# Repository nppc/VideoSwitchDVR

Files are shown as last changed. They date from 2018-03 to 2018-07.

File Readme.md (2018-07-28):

# Control Board for Eachine Pro DVR (to install to EV100 Goggles)

Eachine Pro DVR using separate pins for input and output video signal. This makes it difficult to connect to EV100, where only one pin used for video in and out.

This board helps to automate the switching of video signal in DVR for playback or recording according to EV100 mode.

Also this board delays a startup of DVR for preventing cropping of PAL recording.

There is two additional pads (K1, K3), that can be used for controlling 2 buttons of DVR.

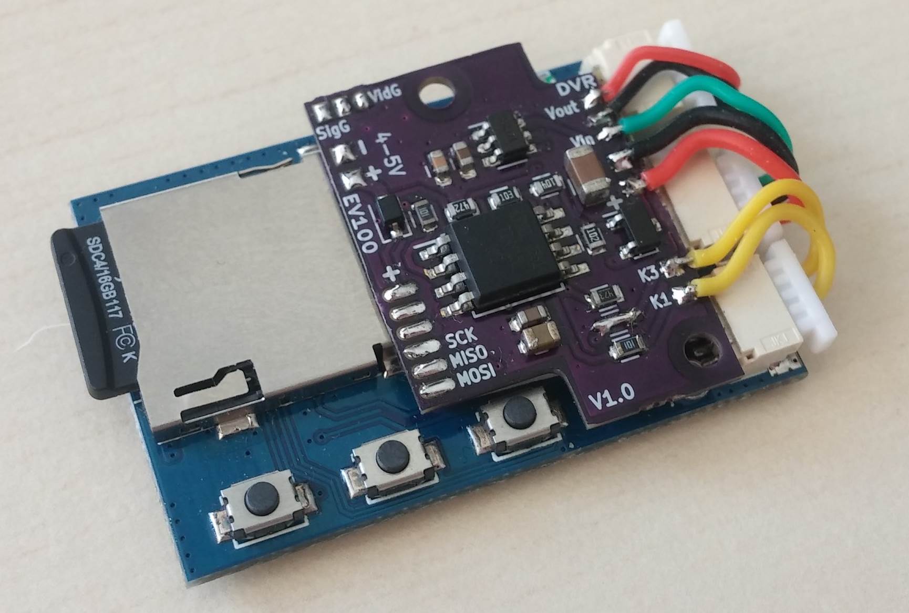
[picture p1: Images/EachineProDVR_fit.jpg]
DVR and PCB


## Current functionality
- When Goggles are powered, power to the DVR is delayed, preventing cropping of recorded video (known as PAL cropping issue).
- If Goggles is in normal mode (signal is coming from VRX), then DVR is receiving the VRX signal.
- If Goggles in AV mode (signal coming from AVin), then DVR starts to send own video to the Goggles.
- Stop recording when Goggles are powered OFF (need to add supercapacitor).
- DVR buttons control: (start recording on power on, switch recording/playback mode automatically).

## Current version of the board
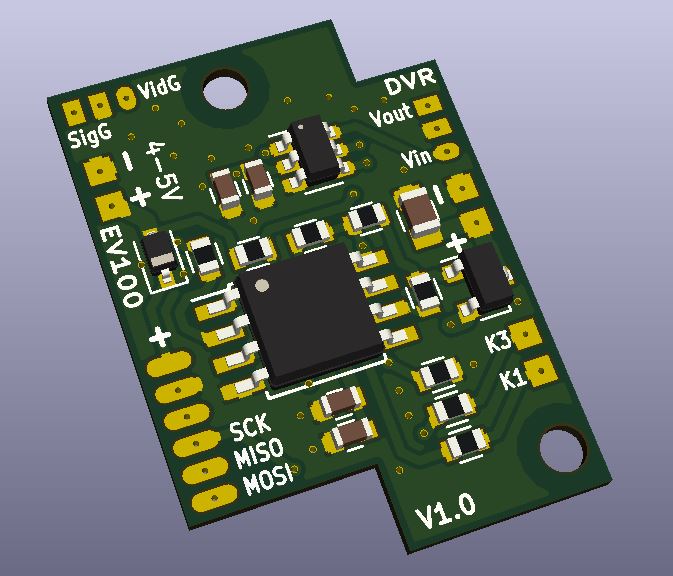
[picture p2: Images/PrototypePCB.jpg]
Current PCB


## Installed in the Goggles
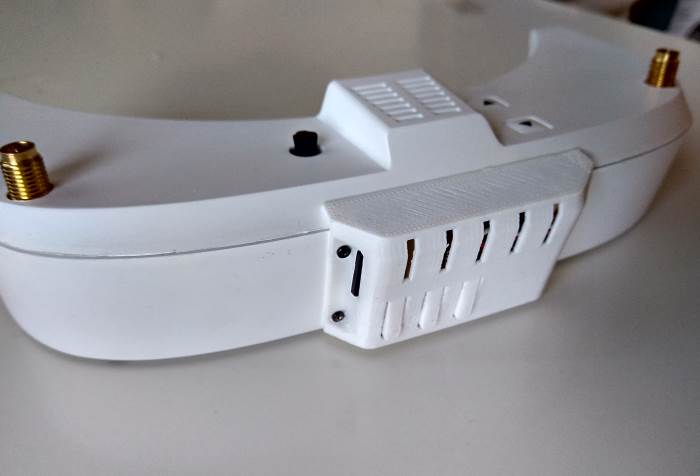
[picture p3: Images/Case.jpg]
printed box


## Power
I'm not sure how powerful is Goggle's DC/DC. So, it is safer to power DVR with additional DC/DC directly from Goggles battery.

Currently I'm using DIY 1A DC/DC with 5.2v output. It's switching frequency is 1.6Mhz, and has no noise in recorded video.
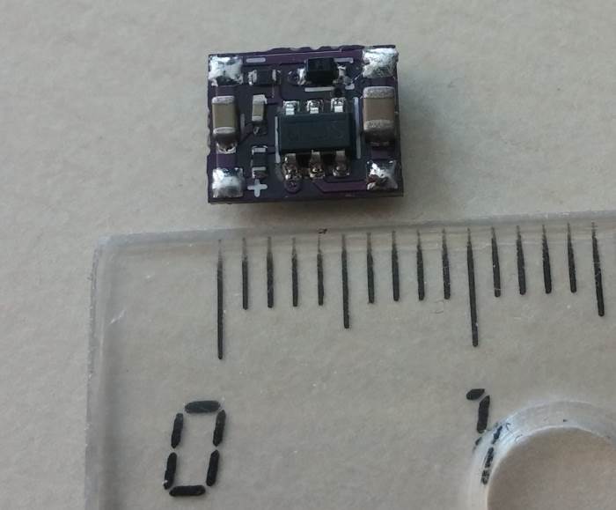
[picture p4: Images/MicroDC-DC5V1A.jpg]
Micro DC/DC 1A 5V


## Connection to the Goggles.
TODO.

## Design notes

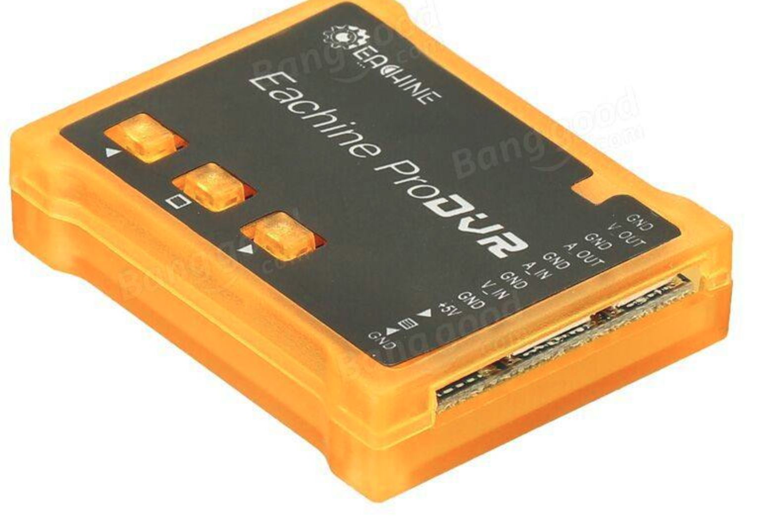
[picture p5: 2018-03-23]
Images/EachineProDVR_OriginalCase.jpg

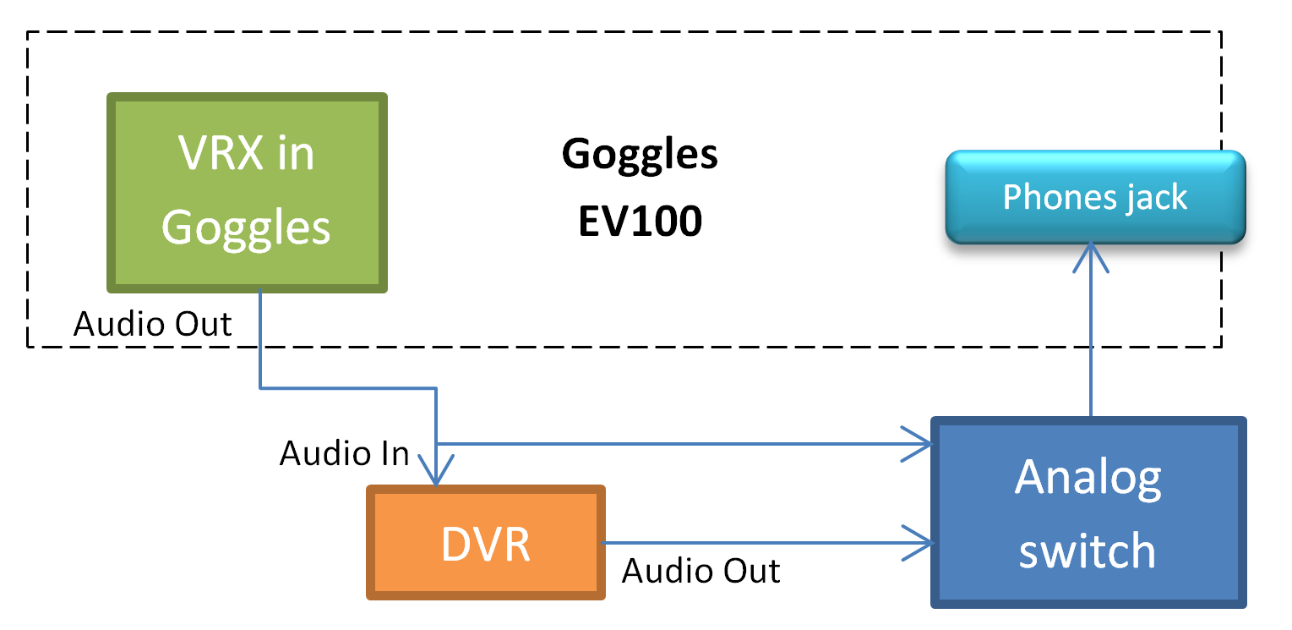
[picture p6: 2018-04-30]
Images/AudioIdea.png

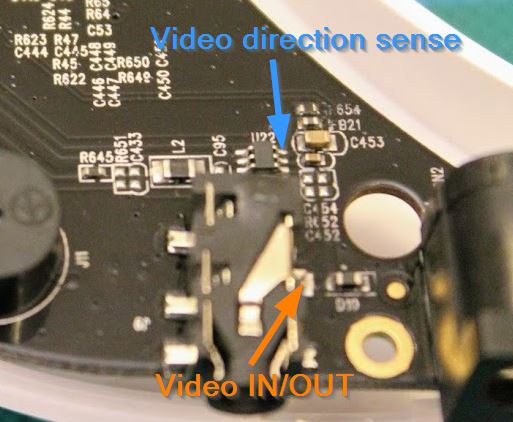
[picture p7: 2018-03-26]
Images/Goggles_connection.jpg

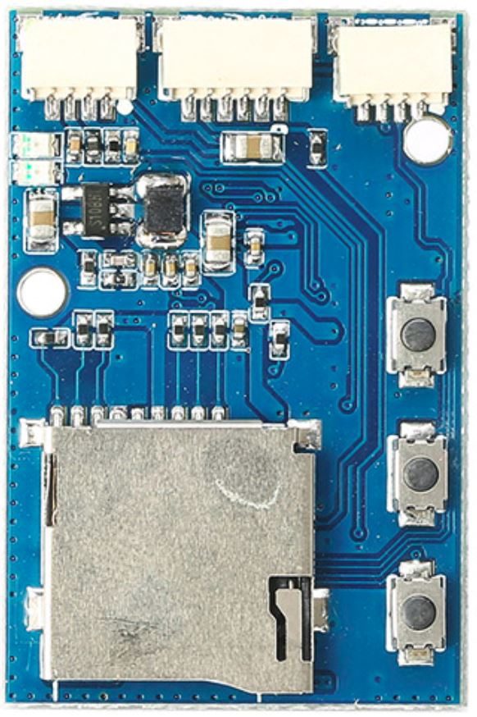
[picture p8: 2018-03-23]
Images/EachineProDVR_PCB.jpg

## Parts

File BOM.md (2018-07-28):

## Bill of Materials

Ref | Value | size/footprint
-------- | ---------------- | ----------
U1 | ATTINY25, ATTINY45 or ATTINY85 | SOIC8
U2 | MAX4624 | SOT-23-6
R2 | 100K | 0603
R4 | 100 | 0603
R6 | 1K | 0603
R7 | 4.7K | 0603
R8 | 47K | 0603
C1 | 10uf | 0603
C2, C3 | 100n | 0603
C4 | 10n | 0603
C5 | 22uf | 0805
D1 | B5819WS (or any with 1A If) | SOD-323
Q1 | AO3415 | SOT-23

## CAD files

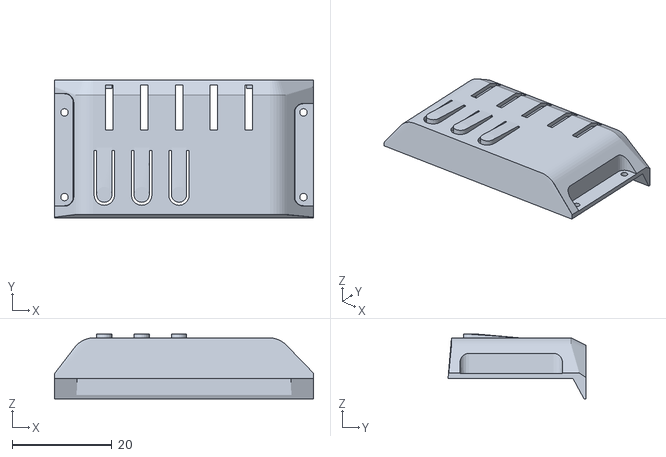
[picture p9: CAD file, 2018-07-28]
SCAD/Case2.stl
52.0 x 27.7 x 12.9

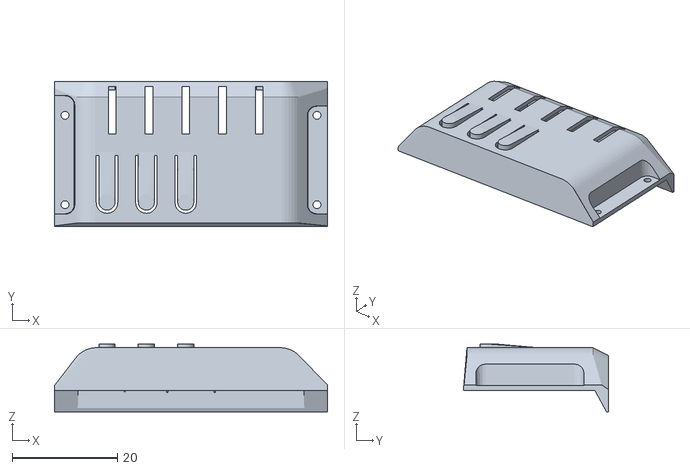
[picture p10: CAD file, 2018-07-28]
SCAD/Case.stl
52.0 x 27.7 x 12.9

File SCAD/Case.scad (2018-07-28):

$fn=20;
//electronics();
//translate([0,0,-25.5])rotate([-11.31,0,0])goggles();
fullcase();

module goggles(){
  color("white")translate([-50,-19,0])hull(){
    cube([100,0.1,20]);
    translate([0,25,5])cube([100,0.1,20]);
    translate([0,30,-1])cube([100,0.1,20]);
  }
}

module fullcase(){
  difference(){
  translate([0,0,1])difference(){
    union(){
      difference(){
        case(0);
        translate([0,0,-0.1])case(0.8); // make a bit thicker top wall
      }
      intersection(){
        case(0);
        union(){
          hull(){
            translate([26,12,0])cylinder(d=5,h=14,center=true);
            translate([26,-14,0])cylinder(d=5,h=14,center=true);
          }
          hull(){
            translate([-22,12,0])cylinder(d=5,h=14,center=true);
            translate([-22,-14,0])cylinder(d=5,h=14,center=true);
          }
        }
      }
      support();
    }
    // mounting holes
    hull(){
      translate([26,7,-2.2])cylinder(d1=3.5,d2=4,h=10);
      translate([26,-10,-2.2])cylinder(d1=3.5,d2=4,h=10);
      translate([30,7,-2.2])cylinder(d1=3.5,d2=4,h=10);
      translate([30,-10,-2.2])cylinder(d1=3.5,d2=4,h=10);
    }
      translate([26,7,0])cylinder(d=1.5,h=10,center=true);
      translate([26,-10,0])cylinder(d=1.5,h=10,center=true);
    hull(){
      translate([-22,9,-2.2])cylinder(d1=3.5,d2=4,h=10);
      translate([-22,-10,-2.2])cylinder(d1=3.5,d2=4,h=10);
      translate([-25,9,-2.2])cylinder(d1=3.5,d2=4,h=10);
      translate([-25,-10,-2.2])cylinder(d1=3.5,d2=4,h=10);
    }
      translate([-22,7,0])cylinder(d=1.5,h=10,center=true);
      translate([-22,-10,0])cylinder(d=1.5,h=10,center=true);

    // sdcard slot
    translate([-20,4.5,0.8])cube([10,12,2.2],center=true);
    
    //translate([0,0,-8.5])cube([100,100,10],center=true);
    //translate([-5,-20,-10])cube([100,100,20]);
  }
    //electronics();
    translate([-38/2+4/2+3,-25/2+4/2+0.9,0]){
      hull(){
        cylinder(d=4.1,h=10); //button
        translate([-4.1/2,5,0])cube([4.1,4,10]);
      }
      translate([7.5,0,0])hull(){
        cylinder(d=4.1,h=10); //button
        translate([-4.1/2,5,0])cube([4.1,4,10]);
      }
      translate([7.5*2,0,0])hull(){
        cylinder(d=4.1,h=10); //button
        translate([-4.1/2,5,0])cube([4.1,4,10]);
      }
    }
    translate([0,0,-25.5])rotate([-11.31,0,0])goggles();
    
    //***** ventilation
    for (i = [0 : 7 : 30] ){
      translate([i-13,8,5])cube([1.5,9,2], center=true);
    }
    /*
    // screw holes
    translate([38/2-7,-25/2+2,0])cylinder(d=1.5,h=5,$fn=20);
    translate([38/2-15.5,25/2-2,0])cylinder(d=1.5,h=5,$fn=20);
    */
    translate([-(20/2+24),0,0])cube([20,100,50],center=true);
    translate([(20/2+28),0,0])cube([20,100,50],center=true);
  }
  // PCB tabs
  //down
  translate([16,12.3,1.2+0.3])cube([3,1,2],center=true);
  translate([-14,12.3,1.2+0.3])cube([3,1,2],center=true);
  translate([19.7+0.5,12.3,-0.6])cube([2,1,2],center=true);
  //side
  hull(){
    translate([-19.1,-9,1.2+0.3])cube([1,3,2],center=true);
    translate([-19.6,-8,1.2+0.3])cube([0.1,3,2],center=true);
  }
  //***** buttons
  translate([-38/2+4/2+3,-25/2+4/2+1,5]){
    button();
    translate([7.5,0,0])button();
    translate([7.5*2,0,0])button();
  }
}


module support(){
  translate([2,-13.2,-2.5])cube([50,0.7,2],center=true);
  
  translate([2,-13.04,-0.1])cube([9,0.8,10],center=true);
  hull(){
  translate([2+9/2,-13.04,-0.1])cube([0.3,0.8,7.8],center=true);
  translate([2+9/2,13,-1+1])cube([0.3,0.8,7],center=true);
  }
  hull(){
  translate([2-9/2,-13.04,-0.1])cube([0.3,0.8,7.8],center=true);
  translate([2-9/2,13,-1+1])cube([0.3,0.8,7],center=true);
  }
  
  translate([-6.6,-12.6,2])cube([8,1.5,4.9],center=true);
  hull(){
  translate([-6.6-3.85,-13.04,1.8])cube([0.3,0.8,4.1],center=true);
  translate([-6.6-4,13,0])cube([0.3,0.8,7],center=true);
  }
}


module button(){
  hull(){
    cylinder(d=3.1,h=1.7); //button
    translate([-3.1/2,5.5,0])cube([3.1,4,1]);
  }
  translate([0,-0.2,-2.7])cylinder(d=2.6,h=2.7);
  
  hull(){
  translate([0,0,-2.7])cylinder(d=2.5,h=2.7);
  translate([0,4,0])cylinder(d=2,h=0.1);
  }
}

module case(wall){
  hull(){
    rotate([90,0,0]){
      translate([-16,0,3/2])cylinder(d=10-wall*2, h=27-3-wall*2,center=true,$fn=50);
      translate([19,0,3/2])cylinder(d=10-wall*2, h=27-3-wall*2,center=true,$fn=50);
      
      translate([-16,0,-(27-3-wall)/2])cylinder(d2=10-wall*2,d1=7-wall, h=3-wall,center=true,$fn=50);
      translate([19,0,-(27-3-wall)/2])cylinder(d2=10-wall*2,d1=7-wall, h=3-wall,center=true,$fn=50);
    }
    translate([2.5,-0.5,-7])cube([60-wall*2,28-wall*2,0.5],center=true);
  }
}

module electronics(){
  difference(){
    union(){
      DVRpcb();
      translate([13.5,-1,0])MYpcb();
    }
    translate([38/2-7,-25/2+2,0])cylinder(d=2,h=10,$fn=20,center=true);
    translate([38/2-7,-25/2+2,-3-0.5])cylinder(d=4,h=3,$fn=20);
    translate([38/2-15.5,25/2-2,0])cylinder(d=2,h=10,$fn=20,center=true);
    translate([38/2-15.5,25/2-2,-3-0.5])cylinder(d=4,h=3,$fn=20);
  }
}

module DVRpcb(){
  color("blue")cube([38,25,1], center=true); // pcb
  color("black")translate([0,0,-(0.5+1.5/2)])cube([36,23,1.5], center=true); // components
  color("lightgray")translate([38/2-1.5,0,(0.5+3/2)])cube([7,24,3], center=true); // connectors
  color("gray")translate([-38/2+15/2+1,25/2-15/2-2,(0.5+2/2)])cube([15,15,2], center=true); // cardreader
  color("black")translate([-38/2+10/2-2,25/2-10/2-3,(0.5+2/2)+0.4])cube([10,10,1], center=true); // sdcard
  
  translate([-38/2+4/2+3,-25/2+2.5/2+1,(0.5+1.5/2)]){
    color("gray")cube([4,2.5,1.5],center=true); //button
    color("black")cylinder(d=1.5,h=1,$fn=10);
  }
  translate([-38/2+4/2+3+7.5,-25/2+2.5/2+1,(0.5+1.5/2)]){
    color("gray")cube([4,2.5,1.5],center=true); //button
    color("black")cylinder(d=1.5,h=1,$fn=10);
  }
  translate([-38/2+4/2+3+7.5+7.5,-25/2+2.5/2+1,(0.5+1.5/2)]){
    color("gray")cube([4,2.5,1.5],center=true); //button
    color("black")cylinder(d=1.5,h=1,$fn=10);
  }
}

module MYpcb(){
  color("purple")translate([-38/2+15/2+1,25/2-15/2-2,(0.5+0.8/2)+2])cube([14,21,0.8], center=true); // cardreader
  color("purple")translate([-38/2+15/2+3.25+4,25/2-15/2-2.25-3.5,(0.5+0.8/2)+2])cube([9.5,21.5,0.8], center=true); // cardreader
  color("black")translate([-10,0,(0.5+1.8/2)+2.8])cube([6,6,1.8], center=true); // cardreader
  
}

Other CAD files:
SCAD/Case2.scad

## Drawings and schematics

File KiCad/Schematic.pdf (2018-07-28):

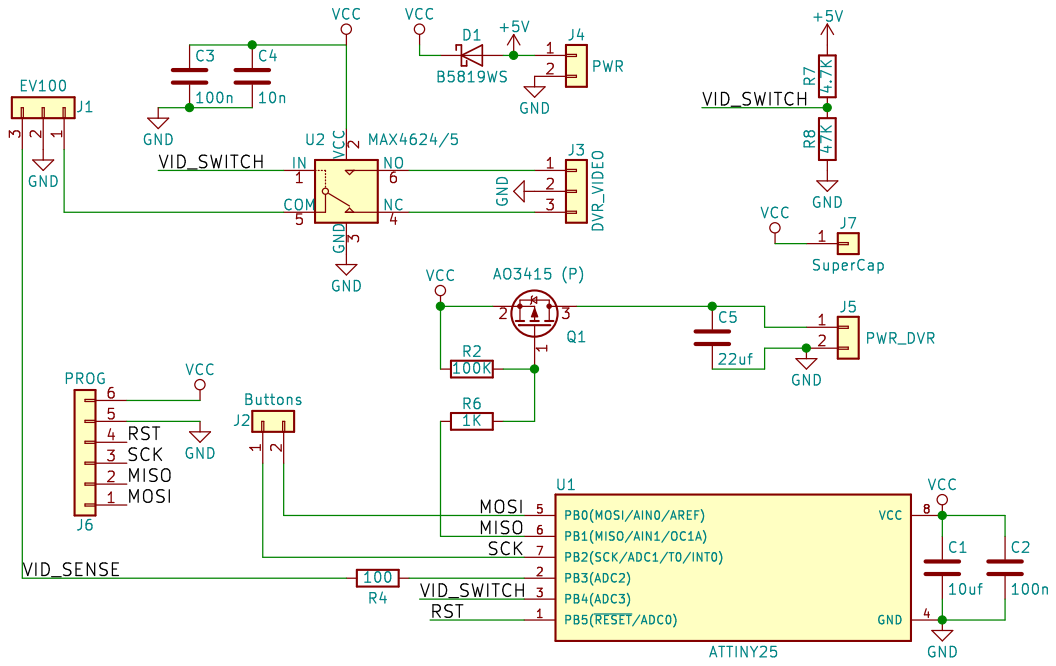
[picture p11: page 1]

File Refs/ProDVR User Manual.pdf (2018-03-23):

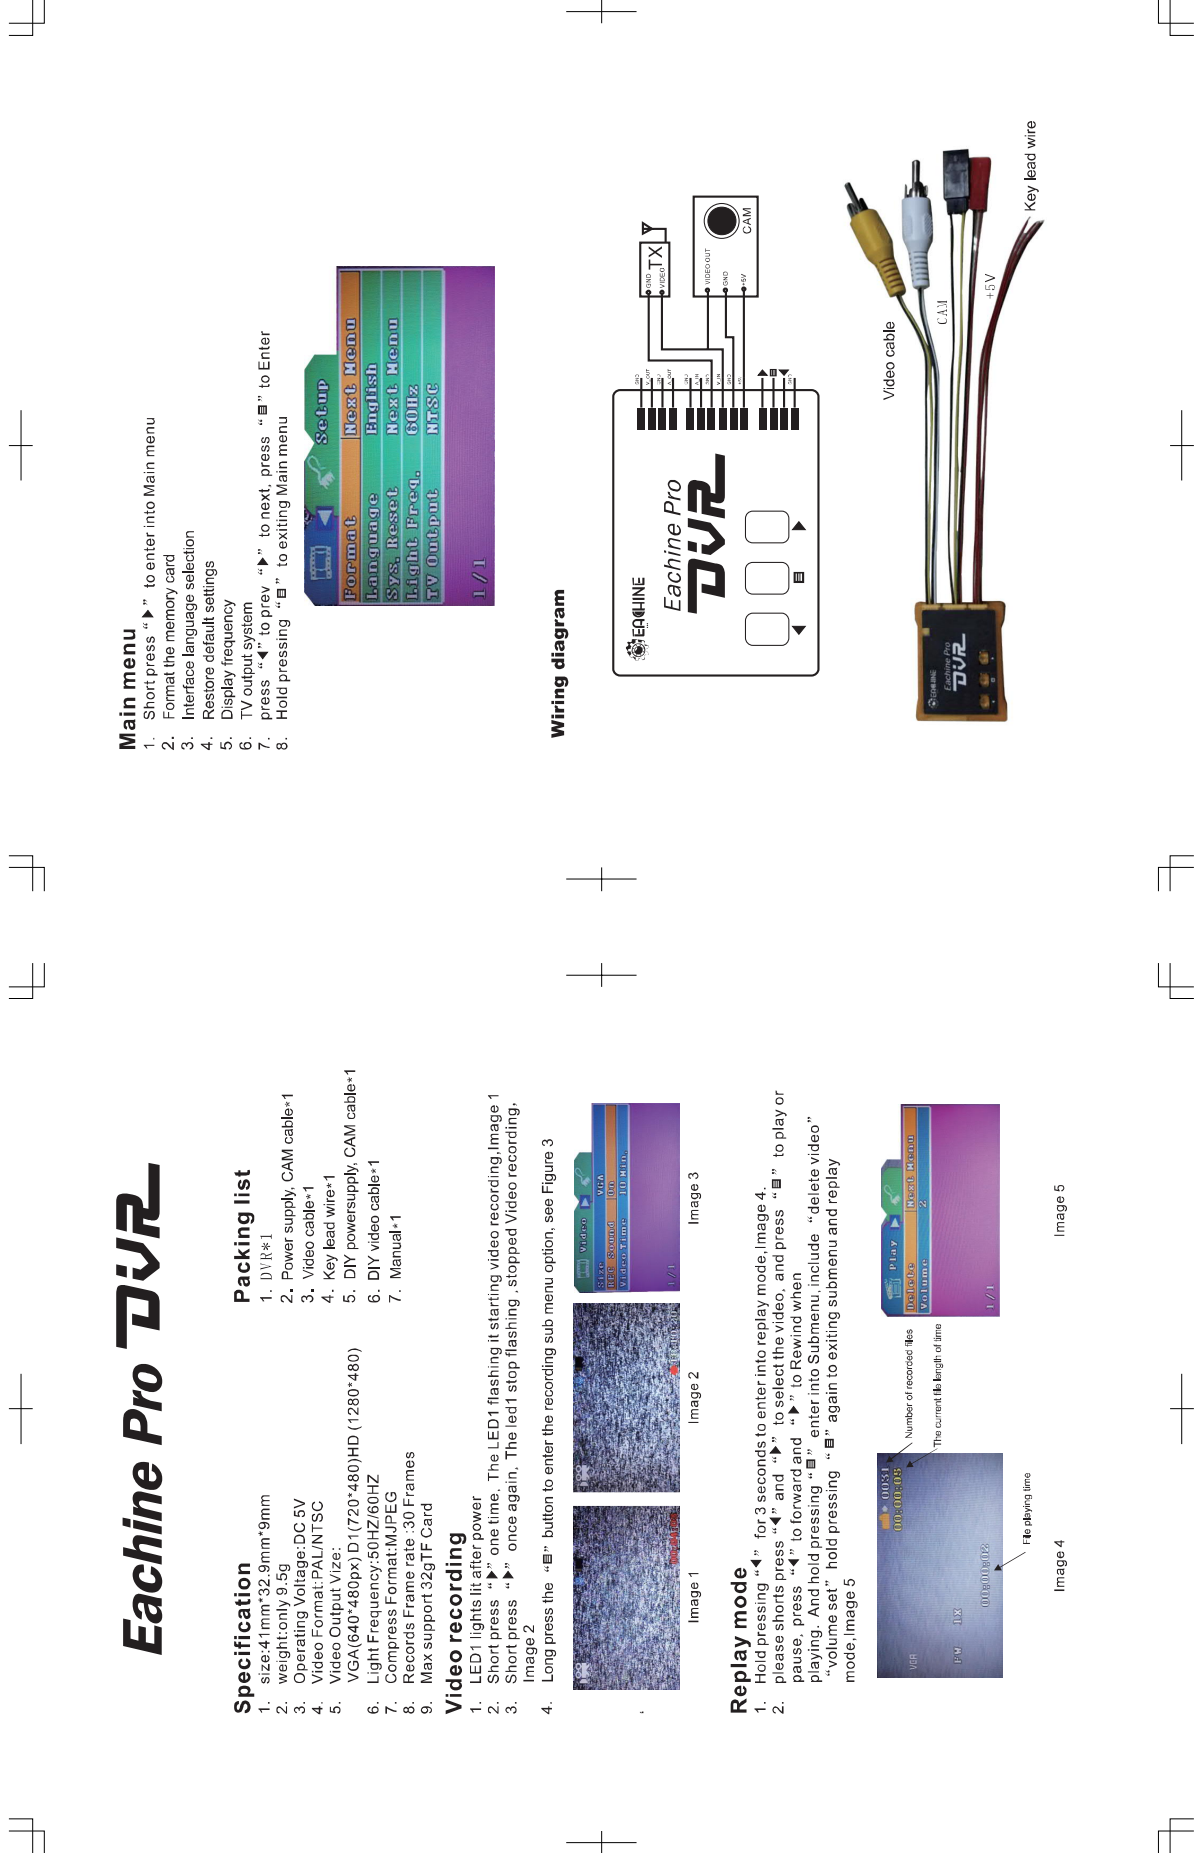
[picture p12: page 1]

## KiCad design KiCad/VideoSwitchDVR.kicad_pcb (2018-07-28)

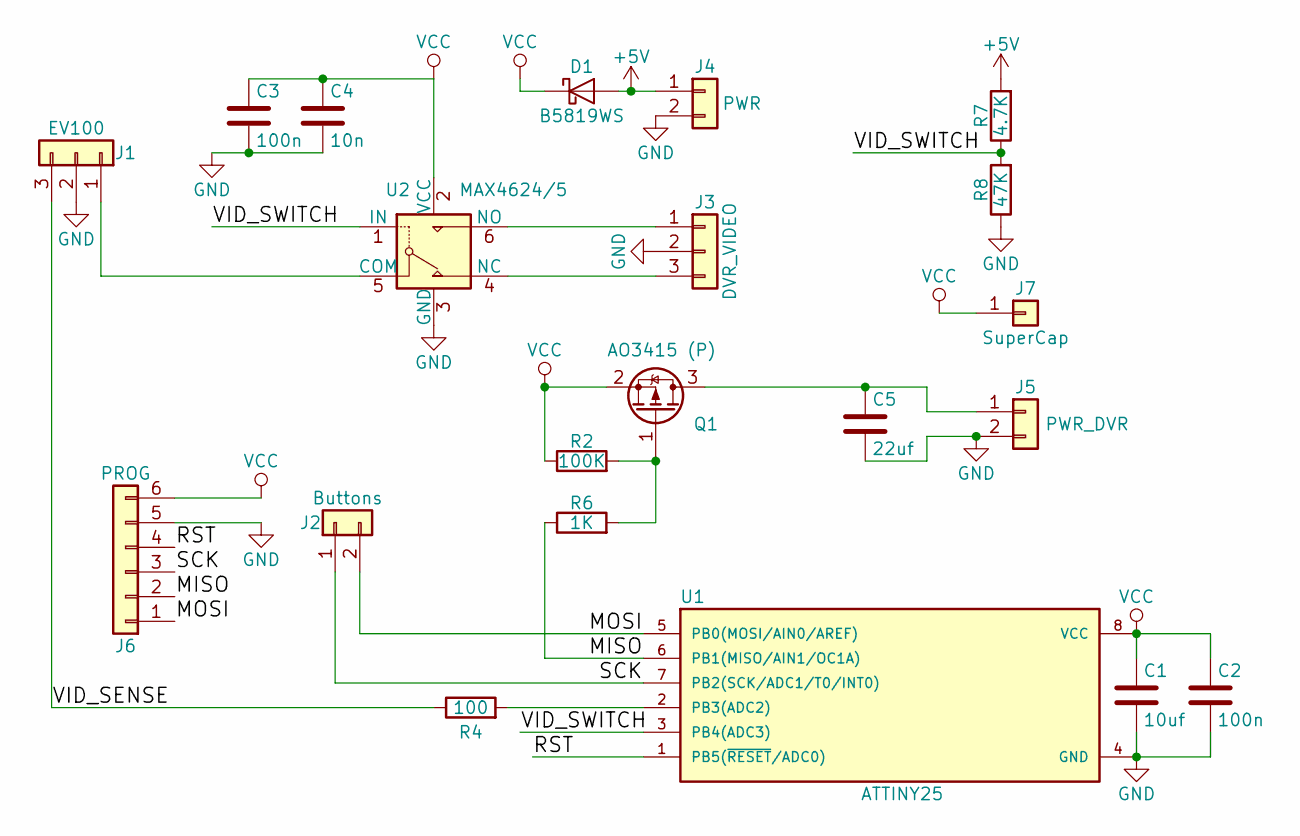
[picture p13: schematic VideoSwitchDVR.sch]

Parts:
C1: 10uf; C_0603
C2, C3: 100n; C_0603
C4: 10n; C_0603
C5: 22uf; C_0805
D1: B5819WS; D_SOD-323
J1: EV100; USB_3_PADS
J2: Buttons; POWER2PIN
J3: DVR_VIDEO; USB_3_PADS
J4: PWR; POWER2PIN
J5: PWR_DVR; POWER2PIN
J6: PROG; Pads_prog_6pin1.25mm
J7: SuperCap; ESC_PWR_PAD
Q1: AO3415 (P); SOT-23
R2: 100K; R_0603
R4: 100; R_0603
R6: 1K; R_0603
R7: 4.7K; R_0603
R8: 47K; R_0603
U1: ATTINY25; SOIJ-8_5.3x5.3mm_Pitch1.27mm
U2: MAX4624/5; SOT-23-6

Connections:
+5V: D1.2 (A), J4.1, R7.2
/MISO: J6.2, R6.1, U1.6 (PB1(MISO/AIN1/OC1A))
/MOSI: J2.2, J6.1, U1.5 (PB0(MOSI/AIN0/AREF))
/RST: J6.4, U1.1 (PB5(~RESET~/ADC0))
/SCK: J2.1, J6.3, U1.7 (PB2(SCK/ADC1/T0/INT0))
/VID_SENSE: J1.3, R4.1
/VID_SWITCH: R7.1, R8.2, U1.3 (PB4(ADC3)), U2.1 (IN)
GND: C1.2, C2.2, C3.2, C4.2, C5.2, J1.2, J3.2, J4.2, J5.2, J6.5, R8.1, U1.4 (GND), U2.3 (GND)
unnamed: C5.1, J5.1, Q1.3 (D)
unnamed: J1.1, U2.5 (COM)
unnamed: J3.1, U2.6 (NO)
unnamed: J3.3, U2.4 (NC)
unnamed: Q1.1 (G), R2.2, R6.2
unnamed: R4.2, U1.2 (PB3(ADC2))
VCC: C1.1, C2.1, C3.1, C4.1, D1.1 (K), J6.6, J7.1, Q1.2 (S), R2.1, U1.8 (VCC), U2.2 (VCC)

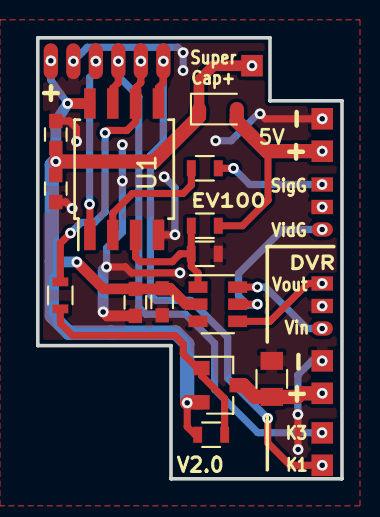
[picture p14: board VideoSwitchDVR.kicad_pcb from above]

Board: 2 copper layers, 16.9 x 24.5 mm, 21 parts (0 on the bottom side), 15 nets.

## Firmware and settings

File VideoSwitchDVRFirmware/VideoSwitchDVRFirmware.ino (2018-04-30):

//#define DEBUG // Debug board (pins routed different)
//#define MODECHANGE_PLAYRECORD // Change DVR mode according to Goggles mode (normal/AV)
#define START_RECORDING // Start recording on power on.
//#define POWERLOSS_STOPRECORDING // Stop recording on power loss.

#define POWERON_DELAY 2000	//ms

// EV100 VIdeo sense signal is HIGH if in AVIN mode
#ifdef DEBUG
	#define PIN_SWITCH_VIDEO 	0	//PB0
	#define PIN_EV100_SIG		3 	//PB3
	#define PIN_DVR_K1			1 	//PB1 (DEBUG LED)
	#define PIN_DVR_K3 			4	//PB4
	#define PIN_DVR_POWER		2	//PB2 (LED)
#else
	#define PIN_SWITCH_VIDEO 	4	//PB4
	#define PIN_EV100_SIG		3 	//PB3
	#define PIN_DVR_K1 			0	//PB0 start/stop recording
	#define PIN_DVR_K3 			2	//PB2 3sec press - enter playback mode
	#define PIN_DVR_POWER		1	//PB1
#endif

#define EV100AV (1<<PIN_EV100_SIG)	// AV Mode when pin PIN_EV100_SIG is HIGH
	
// Pressing button for 2 seconds toggles DVR mode (Record/Playback)
#ifdef DEBUG
	#define LED_DEBUG_ON bitClear(PORTB, PIN_DVR_K1) // LED ON
	#define LED_DEBUG_OFF bitSet(PORTB, PIN_DVR_K1) // LED OFF
#else
	#define DVR_K1_OFF bitClear(DDRB, PIN_DVR_K1) // Button released
	#define DVR_K1_ON bitSet(DDRB, PIN_DVR_K1) // Button pressed
#endif
// Start/stop recording
#define DVR_K3_OFF bitClear(DDRB, PIN_DVR_K3) // Button released
#define DVR_K3_ON bitSet(DDRB, PIN_DVR_K3) // Button pressed
#define DVR_POWER_ON bitClear(PORTB, PIN_DVR_POWER) // DVR POWER ON
#define DVR_POWER_OFF bitSet(PORTB, PIN_DVR_POWER) // DVR POWER OFF

uint8_t DVR_state;	// 0 - recording; anything else - playback
uint8_t EV100_state = 0;

void setup()
{
	DVR_POWER_OFF; // DVR Power is OFF
	bitSet(DDRB,PIN_DVR_POWER);	//  port as output
#ifndef DEBUG
	bitClear(PORTB,PIN_DVR_K1);	// control DVR
	DVR_K1_OFF;
#endif
	bitClear(PORTB,PIN_DVR_K3);	// control DVR
	DVR_K3_OFF;
	bitClear(DDRB,PIN_EV100_SIG);	// listen for signal level pin
	// PIN_SWITCH_VIDEO has a double function.
	// We are listening for power loss and switching video in/out.
	// We need to listen only while recording. So, AVin should be connected when PIN_SWITCH_VIDEO is high (default).
	// PIN_SWITCH_VIDEO is pulled up by Goggle power.
	bitClear(PORTB, PIN_SWITCH_VIDEO); // Video Switch default video from EV100 to DVR (recording)
	bitClear(DDRB, PIN_SWITCH_VIDEO); // Listening for power loss...
	
	#ifdef DEBUG
		// when not connected to EV100. Later we remove pullup.
		bitSet(PORTB, PIN_EV100_SIG); //PullUp
		bitSet(DDRB, PIN_DVR_K1);
		LED_DEBUG_OFF;
	#endif
	
	DVR_state = 0; // After power on we are in recording mode

	#ifdef DEBUG
		LED_DEBUG_ON;
	#endif		
	delay(POWERON_DELAY);
	#ifdef DEBUG
		LED_DEBUG_OFF;
	#endif		
	DVR_POWER_ON;

	#ifdef START_RECORDING
		startRecording();	// delay and start recording
	#endif
	
	ReadEV100state();	// update EV100state variable
}


void loop() {
	// listen for signal level
	ReadEV100state();
	
	// turn video switch according to EV100 state
	if(EV100_state==EV100AV){
		//Active Low
		//bitClear(PORTB, PIN_SWITCH_VIDEO);
		bitSet(DDRB, PIN_SWITCH_VIDEO);
	}else{
		//Floating (Pulled up by external resistor)
		bitClear(DDRB, PIN_SWITCH_VIDEO);
		//bitClear(PORTB, PIN_SWITCH_VIDEO);
	}
	
#ifdef MODECHANGE_PLAYRECORD
	if(EV100_state==EV100AV){
		// switch DVR to PLAY mode. Pressing K3 button for 3 seconds will stop recording and go to PLAY mode.
		DVR_K3_ON;
		#ifdef DEBUG
		LED_DEBUG_ON;
		#endif
		delay(3000);
		DVR_K3_OFF;
		#ifdef DEBUG
		LED_DEBUG_OFF;
		#endif		
		DVR_state=1;	//play
	}else{
		// EV100 mode is normal. Need to  determine, are we just switched from AV?
		if(DVR_state!=0){
			// we need to reboot DVR to make 100% switch to recording mode
			DVR_POWER_OFF;
			delay(2000);
			DVR_POWER_ON;
			DVR_state=0; //record
			#ifdef START_RECORDING
				// If needed let's start recording.
				startRecording();
			#endif
		}
	}
#endif

#ifdef POWERLOSS_STOPRECORDING
	// sense PIN_SWITCH_VIDEO pin only while EV100 in normal mode. If low, then stop recording as soon as possible
	if(EV100_state==0){ // check for power loss only while recording
		if((PINB & (1<<PIN_SWITCH_VIDEO))==0){
			// stop recording
			#ifdef DEBUG
				LED_DEBUG_ON;
			#endif		
			DVR_K1_ON;
			delay(200);
			#ifdef DEBUG
				LED_DEBUG_OFF;
			#endif		
			DVR_K1_OFF;
			while(1){}; //wait until supercapacitor will be empty
		}
	}
#endif
      
	
}


void ReadEV100state(){
	uint8_t new_state = (PINB & (1<<PIN_EV100_SIG));
	delay(50);
	if(new_state == (PINB & (1<<PIN_EV100_SIG))){EV100_state=new_state;}
}

#ifdef START_RECORDING
void startRecording(){
	delay(9000);	// wait while DVR is booting and will be ready for recording
	DVR_K1_ON;
	delay(200);
	DVR_K1_OFF;
}
#endif

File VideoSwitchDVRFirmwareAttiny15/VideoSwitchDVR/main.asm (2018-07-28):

;
; VideoSwitchDVR.asm
;
; Author : Pavel Palonen
;

; Attiny15 runs with default fuses (at 1.6mhz)

;#define DEBUG
#define MODECHANGE_PLAYRECORD ; Change DVR mode according to Goggles mode (normal/AV)
;#define START_RECORDING ; Start recording on power on.
;#define POWERLOSS_STOPRECORDING ; Stop recording on power loss.

#define POWERON_DELAY 2000	;ms
#define DVRBOOT_DELAY 15000	;ms


.include "tn15def.inc"

.equ	PIN_DVR_POWER		= PB1
.equ	PIN_DVR_K1			= PB0
.equ	PIN_DVR_K3			= PB2
.equ	PIN_EV100_SIG		= PB4	; In Attiny25 it is PB3
.equ	PIN_SWITCH_VIDEO	= PB3	; In Attiny25 it is PB4

.def	z0			= r0
.def	z1			= r1
.def	r_sreg		= r2	; Store SREG register in interrupts
.def	DVR_state	= r3	; 0 - recording; anything else - playback
.def	EV100_state = r4
.def	tmp			= r16
.def	tmp1		= r17
.def	tmp2		= r18

#ifdef DEBUG
.def	dbg			= r5
#endif

; Some macros
;DVR_K1_OFF
.MACRO DVR_K1_OFF
	cbi DDRB, PIN_DVR_K1 ; Button released
.ENDMACRO
;DVR_K1_ON
.MACRO DVR_K1_ON
	sbi DDRB, PIN_DVR_K1 ; Button presed
.ENDMACRO
; Start/stop recording
;DVR_K3_OFF
.MACRO DVR_K3_OFF
	cbi DDRB, PIN_DVR_K3 ; Button released
.ENDMACRO
;DVR_K3_ON
.MACRO DVR_K3_ON
	sbi DDRB, PIN_DVR_K3 ; Button pressed
.ENDMACRO
;DVR_POWER_ON
.MACRO DVR_POWER_ON
	cbi PORTB, PIN_DVR_POWER ; DVR POWER ON
.ENDMACRO
;DVR_POWER_OFF
.MACRO DVR_POWER_OFF
	sbi PORTB, PIN_DVR_POWER ; DVR POWER OFF
.ENDMACRO

.EQU EV100AV = (1<<PIN_EV100_SIG)	; AV Mode when pin PIN_EV100_SIG is HIGH

; ***!!!!!*** Hardware Stack in Attiny15 is limited to 3 subsequent subroutine calls or interrupts
.CSEG
.ORG 0
rjmp RESET ; Reset handler
reti	;rjmp EXT_INT0 ; IRQ0 handler
reti	;rjmp PIN_CHANGE ; Pin change handler
reti	;rjmp TIM1_CMP ; Timer1 compare match
reti	;rjmp TIM1_OVF ; Timer1 overflow handler
reti	;rjmp TIM0_OVF ; Timer0 overflow handler
reti	;rjmp EE_RDY ; EEPROM Ready handler
reti	;rjmp ANA_COMP ; Analog Comparator handler
reti	;rjmp ADC ; ADC Conversion Handler

RESET:
	cli
	ldi tmp, 133	; specific for every chip. Chip comes with this value pre-programmed in last eeprom address and last flash address.
	out OSCCAL, tmp
	clr z0
	clr z1
	inc z1
	
; ***** SETUP *****
	; initialize io pins
	DVR_POWER_OFF
	sbi	DDRB, PIN_DVR_POWER	; direction is output
	cbi PORTB, PIN_DVR_K1 ;	control DVR
	DVR_K1_OFF
	cbi PORTB, PIN_DVR_K3 ; control DVR
	DVR_K3_OFF
	cbi DDRB, PIN_EV100_SIG ; listen for signal level pin
	cbi PORTB, PIN_EV100_SIG ; no pullup

	#ifdef DEBUG
		sbi DDRB, PIN_EV100_SIG ; configure as output
		clr dbg
	#endif
	; PIN_SWITCH_VIDEO has a double function.
	; We are listening for power loss and switching video in/out.
	; We need to listen only while recording. So, AVin should be connected when PIN_SWITCH_VIDEO is high (default).
	; PIN_SWITCH_VIDEO is pulled up by Goggle power.
	cbi PORTB, PIN_SWITCH_VIDEO	; Video Switch default video from EV100 to DVR (recording)
	cbi DDRB, PIN_SWITCH_VIDEO ; Listening for power loss...

	; DVR power ON delay
	ldi tmp, POWERON_DELAY/100
	rcall delayNs
	
	DVR_POWER_ON

	; give time to DVR for boot
	ldi tmp, DVRBOOT_DELAY/100
	rcall delayNs

	#ifdef START_RECORDING
		rcall startRecording ; delay and start recording
	#endif
	
	clr DVR_state ; After power on we are in recording mode
	;rcall ReadEV100state ; update EV100state variable

; ***** LOOP *****
loop:
	#ifdef DEBUG
		rcall delay100ms
		inc dbg
		cpse dbg, z0
		rjmp contdbg
		; toggle sigG
		ldi tmp1, (1<<PIN_EV100_SIG)
		in tmp, PORTB
		and tmp, tmp1
		cpse tmp, z0
		cbi PORTB, PIN_EV100_SIG
		cpse tmp, tmp1
		sbi PORTB, PIN_EV100_SIG
		contdbg:
	#endif

	rcall ReadEV100state ; update EV100state variable

	; turn video switch according to EV100 state
	ldi tmp, EV100AV
	cpse EV100_state, tmp
	cbi DDRB, PIN_SWITCH_VIDEO ; Floating (Pulled up by external resistor)
	cpse EV100_state, z0
	sbi DDRB, PIN_SWITCH_VIDEO ; Active Low

	; Define logic for MODECHANGE_PLAYRECORD
	#ifdef MODECHANGE_PLAYRECORD
		ldi tmp, EV100AV
		cpse EV100_state, tmp
		rjmp EV100RecordMode
		cpse DVR_state,z0 ;if we already in play mode, then skip 
		rjmp loopCont1
		; switch DVR to PLAY mode. Pressing K3 button for 3 seconds will stop recording and go to PLAY mode.
		cpse DVR_state,z0
		rjmp loopCont1	; skip if we already in PLAY mode
		DVR_K3_ON
		ldi tmp, 3000/100
		rcall delayNs
		DVR_K3_OFF
		mov DVR_state,z1 ; play
		rjmp loopCont1
	EV100RecordMode:
		; EV100 mode is normal. Need to  determine, are we just switched from AV?
		cpse DVR_state,z1	; if(DVR_state!=0)
		rjmp loopCont1
		; we need to reboot DVR to make 100% switch to recording mode
		DVR_POWER_OFF
		ldi tmp, 2000/100
		rcall delayNs
		DVR_POWER_ON
		; give time to DVR for boot
		ldi tmp, DVRBOOT_DELAY/100
		rcall delayNs		
		mov DVR_state,z0 ; record
		#ifdef START_RECORDING
			; If needed let's start recording.
			rcall startRecording
		#endif
	loopCont1:
	#endif


	#ifdef POWERLOSS_STOPRECORDING
		; sense PIN_SWITCH_VIDEO pin only while EV100 in normal (record) mode. If low, then stop recording as soon as possible
		ldi tmp, EV100AV
		cpse EV100_state, z0 ; check for power loss only while recording
		rjmp loopCont2
		in tmp, PINB ;new_state
		andi tmp, (1<<PIN_SWITCH_VIDEO)
		cpse tmp, z0
		rjmp loopCont2
		; stop recording
		DVR_K1_ON
		rcall delay100ms
		rcall delay100ms
		DVR_K1_OFF
		halt: rjmp halt ; wait until supercapacitor will be empty
	loopCont2:
	#endif
	
	; check if two buttons on DVR are pressed (pulled to GND), then power off DVR. Power it back on when one of the buttons is pressed.
	
rjmp loop


#ifdef START_RECORDING
	startRecording:
		DVR_K1_ON;
		rcall delay100ms
		rcall delay100ms
		DVR_K1_OFF;
		ret
#endif

; We read control pin from EV100 goggles and make sure, this is not a spike
ReadEV100state:
	; read new_state
	in tmp1, PINB ;new_state
	andi tmp1, EV100AV
	clr tmp
	; small delay
RdEV100StateL1:	
	dec tmp
	brne RdEV100StateL1
	; check pin again and update EV100_state accordingly
	in tmp2, PINB ;new_state
	andi tmp2, EV100AV
	cpse tmp1, tmp2
	mov tmp1, EV100_state	; no change to EV100_state
	mov EV100_state, tmp1
	ret

delay100ms:
; 99ms 995us 625 ns at 1.6 MHz (rcall and ret are not included, about 5us)
    ldi  tmp1, 208
    ldi  tmp2, 200
d100ms: 
	dec  tmp2
    brne d100ms
    dec  tmp1
    brne d100ms
	ret
	
; Delay subroutine
; Input variable: tmp = ms/100	
delayNs:
dNs:rcall delay100ms
    dec  tmp
    brne dNs
	ret

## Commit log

2018-01-15 Add KiCad project
    [VideoSwitchDVR.kicad_pcb, VideoSwitchDVR.sch]
2018-01-16 Some progress on PCB. MCU changed to simplier one
    [VideoSwitchDVR.kicad_pcb, VideoSwitchDVR.sch]
2018-03-22 Some work
    [VideoSwitchDVR.kicad_pcb, VideoSwitchDVR.sch]
2018-03-23 invert logic of Video switch
    [VideoSwitchDVRFirmware.ino]
2018-03-23 Now can use two buttons and power loss sensing at the same time
    [VideoSwitchDVR.kicad_pcb, VideoSwitchDVR.sch]
2018-03-24 Idea with combined sensning and video switch on one pin is working
2018-03-24 K1, K3 buttons are clarified
2018-03-26 Schematic as png
2018-04-30 alfa version is 90% tested
    [VideoSwitchDVR.sch]
2018-05-03 PCB 2.0. Case SCAD.
    [Case.scad, Case.stl, VideoSwitchDVR.kicad_pcb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]
2018-05-07 3D printed case finished
    [Case2.scad, Case2.stl]
2018-05-07 After first power ON we also need to wait for DVR boot
2018-07-28 BOM and pdf schematic added
